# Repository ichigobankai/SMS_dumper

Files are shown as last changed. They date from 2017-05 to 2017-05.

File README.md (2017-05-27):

# SMS dumper

This project is a very low cost USB reader/writer(1) for Sega Master System cartridges.
HID code is based on libopencm3 ARM Lib & paulfertser/stm32-tx-hid ( https://github.com/paulfertser/stm32-tx-hid)

Support :
* Sega Master System mapper (Sms/Mark3, SG-1000/SC-3000/Othello Multivision)
* Codemasters mapper
* Korean "large" mapper (type Jang Pung III)
* Read and write S-ram (Master System Mapper)
* can re-write flash eprom on my pcb(1)

Speed (can vary depend on USB) :
* Dump 128kB : 4s
* write 128kB : 21s (erase/write and verif)(1)

(1)only working with my sega mapper clone/pcb

This firmware is targetting the cheapest STM32F103 board as found in
numerous listings on eBay and Aliexpress (might have the following
keywords: ARM STM32F103C8T6 Minimum System Development Board Module
For Arduino).

* Board description
The board has an STM32F103C8T6 controller for USB communication
(no drivers needed, connected in HID) 
It uses two 74LS273 for multiplexing i/o data lines into address lines.

* Building the firmware
After cloning the repository "git submodule init; git submodule
update" needs to be run once, then "build.sh" to build everything
necessary.

It is assumed that "arm-none-eabi" toolchain is available in PATH,
"GCC ARM Embedded" is the recommended option. In case you need to
specify a path, CROSS_COMPILE make variable should be set
appropriately.

* Initial flashing procedure
There're two ways of flashing a blank board: via SWD and via serial
bootloader. For the first method a suitable debug adapter is needed
(e.g. ST-Link or J-Link), for the second one can use just about any
USB-UART bridge (the only requirement that is a bit unusual is to
support "even" parity).

The image to be flashed is "smsdumper_stm32_bootANDsoft.bin", it
contains both a DFU-compliant bootloader and the main firmware. 

If you have any suggestions or questions, feel free to contact me
directly via email.

Ichigo <github@ultimate-consoles.fr>

My friend X-death have made a silimar dumper but for Megadrive/Genesis (Md Dumper)

Available on his Github page : https://github.com/X-death25/STM32_Projects/tree/master/Megadrive_HID

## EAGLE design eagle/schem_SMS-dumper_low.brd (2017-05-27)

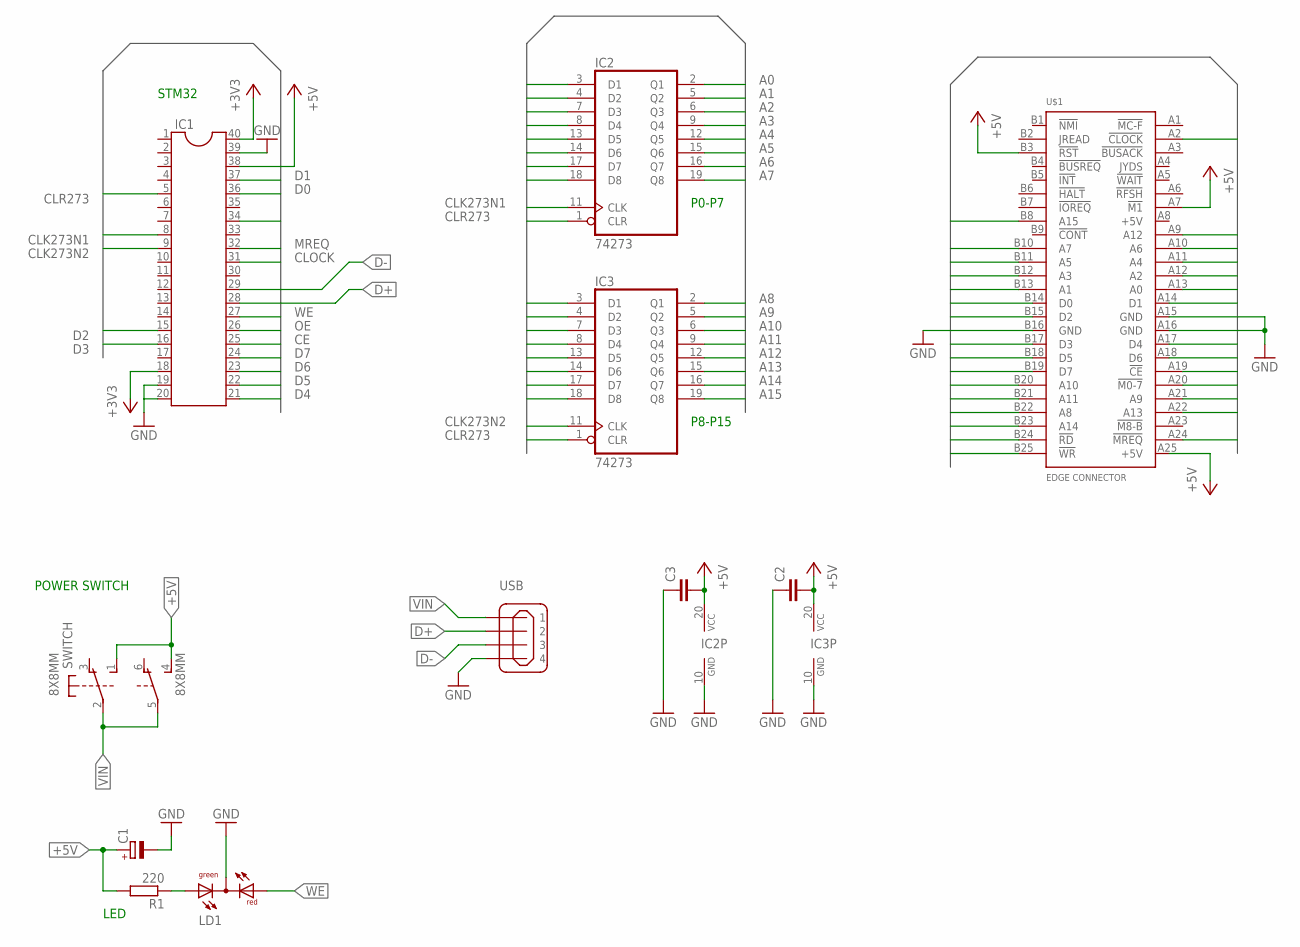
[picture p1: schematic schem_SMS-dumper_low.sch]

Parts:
8X8MM: SWITCH; PVA2F
C1: CPOL-EUE2,5-6E; E2,5-6E
C2, C3: C-EU050-024X044; C050-024X044
IC1: DIL40
IC2, IC3: 74273; DIL20
LD1: DUOLED-RG-C; DUOLED-C-5MM
R1: 220; 0204/7
U$1: EDGE CONNECTOR; CARD50F
USB: MINI-USB_4P-85-32004-10X; 85-32004-10X

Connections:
+3V3: IC1.18, IC1.40
+5V: 8X8MM.1 (S), 8X8MM.4 (S), C1.+, C2.2, C3.2, IC1.38, IC2.20 (VCC), IC3.20 (VCC), R1.2, U$1.A7 (!M1), U$1.A25 (+5V), U$1.B3 (!RST)
A0: IC2.2 (Q1), U$1.A13 (A0)
A1: IC2.5 (Q2), U$1.B13 (A1)
A2: IC2.6 (Q3), U$1.A12 (A2)
A3: IC2.9 (Q4), U$1.B12 (A3)
A4: IC2.12 (Q5), U$1.A11 (A4)
A5: IC2.15 (Q6), U$1.B11 (A5)
A6: IC2.16 (Q7), U$1.A10 (A6)
A7: IC2.19 (Q8), U$1.B10 (A7)
A8: IC3.2 (Q1), U$1.B22 (A8)
A9: IC3.5 (Q2), U$1.A21 (A9)
A10: IC3.6 (Q3), U$1.B20 (A10)
A11: IC3.9 (Q4), U$1.B21 (A11)
A12: IC3.12 (Q5), U$1.A9 (A12)
A13: IC3.15 (Q6), U$1.A22 (A13)
A14: IC3.16 (Q7), U$1.B23 (A14)
A15: IC3.19 (Q8), U$1.B8 (A15)
CE: IC1.25, U$1.A19 (!CE)
CLK273N1: IC1.8, IC2.11 (CLK)
CLK273N2: IC1.9, IC3.11 (CLK)
CLOCK: IC1.31, U$1.A2 (!CLOCK)
CLR273: IC1.5, IC2.1 (CLR), IC3.1 (CLR)
D0: IC1.36, IC2.3 (D1), IC3.3 (D1), U$1.B14 (D0)
D1: IC1.37, IC2.4 (D2), IC3.4 (D2), U$1.A14 (D1)
D2: IC1.15, IC2.7 (D3), IC3.7 (D3), U$1.B15 (D2)
D3: IC1.16, IC2.8 (D4), IC3.8 (D4), U$1.B17 (D3)
D4: IC1.21, IC2.13 (D5), IC3.13 (D5), U$1.A17 (D4)
D5: IC1.22, IC2.14 (D6), IC3.14 (D6), U$1.B18 (D5)
D6: IC1.23, IC2.17 (D7), IC3.17 (D7), U$1.A18 (D6)
D7: IC1.24, IC2.18 (D8), IC3.18 (D8), U$1.B19 (D7)
D+: IC1.28, USB.2
D-: IC1.29, USB.3
GND: C1.-, C2.1, C3.1, IC1.19, IC1.20, IC1.39, IC2.10 (GND), IC3.10 (GND), U$1.A15 (GND), U$1.A16 (GND), U$1.B16 (GND), USB.4
M0-7: IC1.34, U$1.A20 (!M0-7)
MREQ: IC1.32, U$1.A24 (!MREQ)
unnamed: LD1.AX (AG), R1.1
OE: IC1.26, U$1.B24 (!RD)
VIN: 8X8MM.2, 8X8MM.5, USB.1
WE: IC1.27, LD1.AR, U$1.B25 (!WR)

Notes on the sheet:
STM32
P0-P7
P8-P15
POWER SWITCH
LED

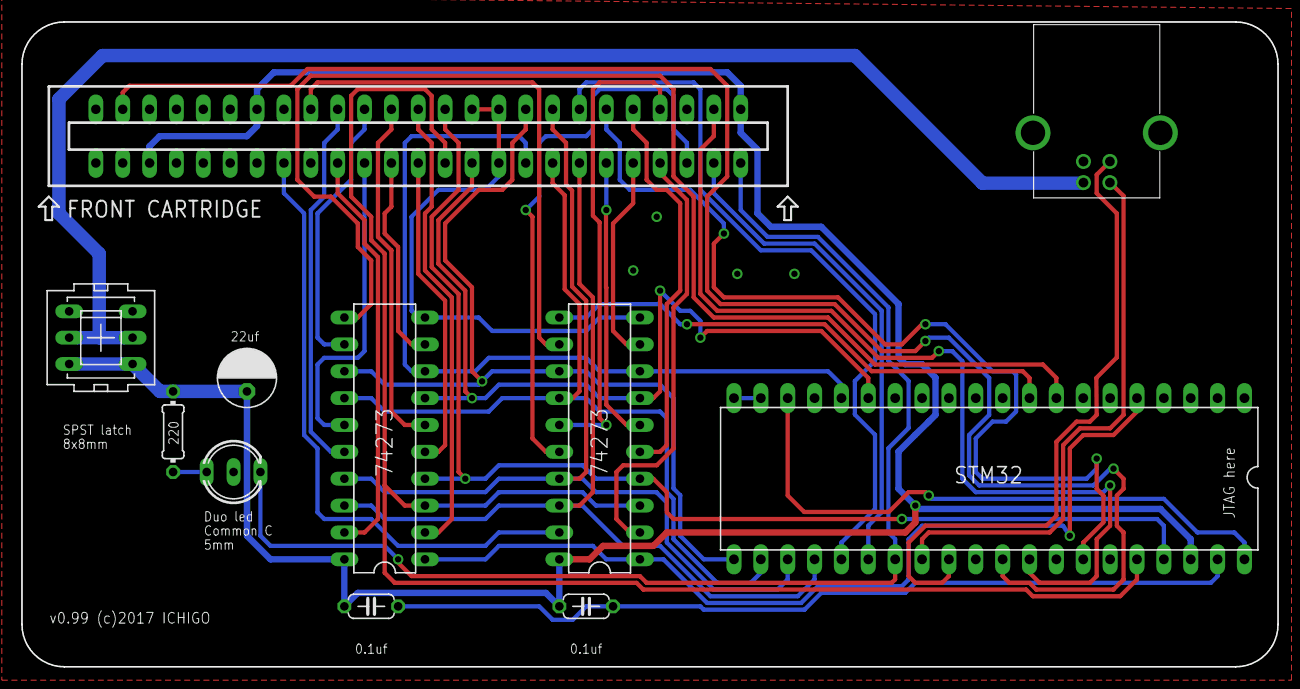
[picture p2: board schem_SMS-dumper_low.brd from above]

Board: 2 copper layers, 118.7 x 61.0 mm, 11 parts (0 on the bottom side), 40 nets.

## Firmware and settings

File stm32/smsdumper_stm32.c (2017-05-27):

/*  
SMS dumper v0
STM32F103CT8
*/

#include <string.h>
#include <libopencm3/stm32/rcc.h>
#include <libopencm3/stm32/exti.h>
#include <libopencm3/stm32/gpio.h>
#include <libopencm3/stm32/flash.h>
#include <libopencm3/stm32/adc.h>
#include <libopencm3/stm32/pwr.h>
#include <libopencm3/usb/usbd.h>
#include <libopencm3/usb/hid.h>
#include <libopencm3/stm32/st_usbfs.h>
#include <libopencm3/cm3/systick.h>
#include <libopencm3/cm3/nvic.h>
#include <libopencmsis/core_cm3.h>

#include <libopencm3/cm3/scb.h>
#include <libopencm3/usb/dfu.h>

#define D0 GPIO8  // PB8
#define D1 GPIO9  // PB9
#define D2 GPIO10 // PB10
#define D3 GPIO11 // PB11
#define D4 GPIO12 // PB12
#define D5 GPIO13 // PB13
#define D6 GPIO14 // PB14
#define D7 GPIO15 // PB15

#define CE GPIO8  //PA8
#define OE GPIO9  //PA9
#define WE GPIO10 //PA10

#define CLOCK GPIO3 //PB3  	- only for codemasters
#define MREQ GPIO4 //PB4   	- only for codemasters and MK3
#define M7 GPIO6 //PB6		- M0-7

#define CLEAR_273 GPIO0  // PA0
#define CLK_273N1 GPIO3  // PA3 
#define CLK_273N2 GPIO4  // PA4

#define SMS_WAKEUP    		0x11  // WakeUP STM32
#define SMS_READ      		0x12  // Read
#define SMS_WRITE_SRAM     	0x13  // Write
#define SMS_WRITE_FLASH     0x14  // Write Flash
#define SMS_ERASE_FLASH     0x15  // Write Flash
//#define SMS_FLASH_ID   	  	0x16  // Chip ID

#define CLEAR_ALL_PINS	0x44444444

// We need a special large control buffer for this device:
unsigned char usbd_control_buffer[5*64];

unsigned char buffer_in[64];
unsigned char buffer_out[64];
const unsigned char buffer_zeroed[64] = {0}; 
unsigned char hid_interrupt = 0;
unsigned int address = 0; //0xFFFF max

static usbd_device *usbd_dev;
static char serial_no[25];

const struct usb_device_descriptor dev_descr =
{
    .bLength = USB_DT_DEVICE_SIZE,
    .bDescriptorType = USB_DT_DEVICE,
    .bcdUSB = 0x0200,
    .bDeviceClass = 0,
    .bDeviceSubClass = 0,
    .bDeviceProtocol = 0,
    .bMaxPacketSize0 = 64,
    .idVendor = 0x0483,
    .idProduct = 0x5750,
    .bcdDevice = 0x0200,
    .iManufacturer = 1,
    .iProduct = 2,
    .iSerialNumber = 3,
    .bNumConfigurations = 1,
};

static const uint8_t hid_report_descriptor[] =
{

    0x06, 0x00, 0xFF,  // Usage Page (Vendor Defined 0xFF00)
    0x09, 0x01,        // Usage (0x01)
    0xA1, 0x01,        // Collection (Application)
    0x19, 0x01,        // Usage Minimum (0x01)
    0x29, 0x40,        // Usage Maximum (0x40)
    0x15, 0x00,        // Logical Minimum (0)
    0x26, 0xFF, 0x00,  // Logical Maximum (255)
    0x75, 0x08,        // Report Size (8)
    0x95, 0x40,        // Report Count (64)
    0x81, 0x00,        // Input (Data,Array,Abs,No Wrap,Linear,Preferred State,No Null Position)
    0x19, 0x01,        // Usage Minimum (0x01)
    0x29, 0x40,        // Usage Maximum (0x40)
    0x91, 0x00,        // Output (Data,Array,Abs,No Wrap,Linear,Preferred State,No Null Position,Non-volatile)
    0xC0,              // End Collection
};

static const struct
{
    struct usb_hid_descriptor hid_descriptor;
    struct
    {
        uint8_t bReportDescriptorType;
        uint16_t wDescriptorLength;
    } __attribute__((packed)) hid_report;
} __attribute__((packed)) hid_function =
{
    .hid_descriptor = {
        .bLength = sizeof(hid_function),
        .bDescriptorType = USB_DT_HID,
        .bcdHID = 0x0100,
        .bCountryCode = 0,
        .bNumDescriptors = 1,
    },
    .hid_report = {
        .bReportDescriptorType = USB_DT_REPORT,
        .wDescriptorLength = sizeof(hid_report_descriptor),
    }
};

const struct usb_endpoint_descriptor hid_endpoint[] =
{
    {
        .bLength = USB_DT_ENDPOINT_SIZE,
        .bDescriptorType = USB_DT_ENDPOINT,
        .bEndpointAddress = 0x81,
        .bmAttributes = USB_ENDPOINT_ATTR_INTERRUPT,
        .wMaxPacketSize = 64,
        .bInterval = 0x01,
    },
    {
        .bLength = USB_DT_ENDPOINT_SIZE,
        .bDescriptorType = USB_DT_ENDPOINT,
        .bEndpointAddress = 0x01,
        .bmAttributes = USB_ENDPOINT_ATTR_INTERRUPT,
        .wMaxPacketSize = 64,
        .bInterval = 0x01,
    }

};

const struct usb_interface_descriptor hid_iface =
{
    .bLength = USB_DT_INTERFACE_SIZE,
    .bDescriptorType = USB_DT_INTERFACE,
    .bInterfaceNumber = 0,
    .bAlternateSetting = 0,
    .bNumEndpoints = 2,
    .bInterfaceClass = USB_CLASS_HID,
    .bInterfaceSubClass = 0, // boot
    .bInterfaceProtocol = 0, // mouse
    .iInterface = 0,

    .endpoint = hid_endpoint, // fix 2

    .extra = &hid_function,
    .extralen = sizeof(hid_function),
};

const struct usb_dfu_descriptor dfu_function =
{
    .bLength = sizeof(struct usb_dfu_descriptor),
    .bDescriptorType = DFU_FUNCTIONAL,
    .bmAttributes = USB_DFU_CAN_DOWNLOAD | USB_DFU_WILL_DETACH,
    .wDetachTimeout = 255,
    .wTransferSize = 1024,
    .bcdDFUVersion = 0x011A,
};

const struct usb_interface_descriptor dfu_iface =
{
    .bLength = USB_DT_INTERFACE_SIZE,
    .bDescriptorType = USB_DT_INTERFACE,
    .bInterfaceNumber = 1,
    .bAlternateSetting = 0,
    .bNumEndpoints = 0,
    .bInterfaceClass = 0xFE,
    .bInterfaceSubClass = 1,
    .bInterfaceProtocol = 1,
    // The ST Microelectronics DfuSe application needs this string.
    // The format isn't documented...
    .iInterface = 4,

    .extra = &dfu_function,
    .extralen = sizeof(dfu_function),
};

const struct usb_interface ifaces[] = {{
        .num_altsetting = 1,
        .altsetting = &hid_iface,
    }, {
        .num_altsetting = 1,
        .altsetting = &dfu_iface,
    }
};

const struct usb_config_descriptor config =
{
    .bLength = USB_DT_CONFIGURATION_SIZE,
    .bDescriptorType = USB_DT_CONFIGURATION,
    .wTotalLength = 0,
    .bNumInterfaces = 2,
    .bConfigurationValue = 1,
    .iConfiguration = 0,
    .bmAttributes = 0xC0,
    .bMaxPower = 0x32,

    .interface = ifaces,
};

static int hid_control_request(usbd_device *dev, struct usb_setup_data *req, uint8_t **buf, uint16_t *len,
                               void (**complete)(usbd_device *dev, struct usb_setup_data *req))
{
    (void)complete;
    (void)dev;

    if((req->bmRequestType != 0x81) ||
            (req->bRequest != USB_REQ_GET_DESCRIPTOR) ||
            (req->wValue != 0x2200))
        return 0;

    // Handle the HID report descriptor.
    *buf = (uint8_t *)hid_report_descriptor;
    *len = sizeof(hid_report_descriptor);

    return 1;
}

static void dfu_detach_complete(usbd_device *dev, struct usb_setup_data *req)
{
    (void)req;
    (void)dev;

    scb_reset_core();
}

static int dfu_control_request(usbd_device *dev, struct usb_setup_data *req, uint8_t **buf, uint16_t *len,
                               void (**complete)(usbd_device *dev, struct usb_setup_data *req))
{
    (void)buf;
    (void)len;
    (void)dev;

    if ((req->bmRequestType != 0x21) || (req->bRequest != DFU_DETACH))
        return 0; // Only accept class request.

    *complete = dfu_detach_complete;

    return 1;
}

static void hid_set_config(usbd_device *dev, uint16_t wValue)
{
    (void)wValue;

    usbd_ep_setup(dev, 0x81, USB_ENDPOINT_ATTR_INTERRUPT, 64, NULL);
    usbd_ep_setup(dev, 0x01, USB_ENDPOINT_ATTR_INTERRUPT, 64, NULL);

    usbd_register_control_callback(
        dev,
        USB_REQ_TYPE_STANDARD | USB_REQ_TYPE_INTERFACE,
        USB_REQ_TYPE_TYPE | USB_REQ_TYPE_RECIPIENT,
        hid_control_request);
    usbd_register_control_callback(
        dev,
        USB_REQ_TYPE_CLASS | USB_REQ_TYPE_INTERFACE,
        USB_REQ_TYPE_TYPE | USB_REQ_TYPE_RECIPIENT,
        dfu_control_request);

    //systick configuration

    // 72MHz / 8 => 9000000 counts per second : 9 Mhz
    systick_set_clocksource(STK_CSR_CLKSOURCE_AHB_DIV8);
    STK_CVR = 0;
    systick_set_reload(8999);
    systick_interrupt_enable();
    systick_counter_enable();
}

static const char *usb_strings[] =
{
    "libopencm3",
    "SMS Dumper",
    serial_no,
    // This string is used by ST Microelectronics' DfuSe utility.
    "@Internal Flash   /0x08000000/8*001Ka,56*001Kg",
};

static char *get_dev_unique_id(char *s)
{
    volatile uint8_t *unique_id = (volatile uint8_t *)0x1FFFF7E8;
    int i;

    // Fetch serial number from chip's unique ID
    for(i = 0; i < 24; i+=2)
    {
        s[i] = ((*unique_id >> 4) & 0xF) + '0';
        s[i+1] = (*unique_id++ & 0xF) + '0';
    }
    for(i = 0; i < 24; i++)
        if(s[i] > '9')
            s[i] += 'A' - '9' - 1;

    return s;
}



void wait(unsigned char n){
    while(n){ 
    	__asm__("nop"); 
    	n--;
    }
}


void enable_cart(){
	GPIO_BRR(GPIOA) |= (CE | OE);
}

void disable_cart(){
	GPIO_BSRR(GPIOA) |= (CE | OE);
}


void mapper_write_register(){
	
    //set adr MAPPER register
    GPIO_CRH(GPIOB) = 0x33333333; //set pb8-15 as data OUT
  
    GPIO_ODR(GPIOB) = (buffer_in[5]<<8); //MAPPER adr low
    GPIO_BRR(GPIOA)  |= CLK_273N1;
    GPIO_BSRR(GPIOA) |= CLK_273N1;

    GPIO_ODR(GPIOB) = (buffer_in[6]<<8); //MAPPER adr hi
   	GPIO_BRR(GPIOA)  |= CLK_273N2;
   	GPIO_BSRR(GPIOA) |= CLK_273N2;
   	
    GPIO_ODR(GPIOB) = (buffer_in[4]<<8); //MAPPER page D0-D7
   	enable_cart();
	if((buffer_in[7]==3 && address>0x7FFF) && hid_interrupt==SMS_READ){  //4Pak mapper
		GPIO_BSRR(GPIOB) |= M7 | (MREQ << 16); 
		}else{ 
		GPIO_BRR(GPIOB) |= M7 | MREQ; 
	}
	if(buffer_in[7]==1 && hid_interrupt==SMS_READ){ GPIO_BSRR(GPIOB) |= M7; }
	GPIO_BRR(GPIOA) |= WE;
	if(buffer_in[7]==2 && hid_interrupt==SMS_READ){ //codemasters mapper
		GPIO_BRR(GPIOB) |= CLOCK;
		GPIO_BSRR(GPIOB) |= CLOCK;
	}
    __asm__("nop");
	GPIO_BSRR(GPIOA) |= WE;
	disable_cart();
}


void read_cartridge(){
  	unsigned char adr = 0;

    GPIO_CRL(GPIOA) = 0x44433443; //out Clk1-3, et MRclear
	GPIO_CRH(GPIOA) = 0x44444333; //all out CE, etc. 50mhz
	GPIO_CRL(GPIOB) = 0x43433444;  //set clock/mreq for codemasters mapper, M0-7(=A15 on some MS old games)
  	
	//Clk273n1, Clk273n2, Clk273n3, WE = High - Clear273
  	GPIO_BSRR(GPIOA) |= (CLK_273N1 | CLK_273N2 | WE | CE | OE) | (CLEAR_273 << 16);
    GPIO_BSRR(GPIOA) |= CLEAR_273; //active 273.
	
	if(buffer_in[7]==2){ //codemasters
		GPIO_BSRR(GPIOB) |= CLOCK | (MREQ << 16); 
	}
	
	if(buffer_in[3]){ mapper_write_register(); }

 	while(adr < 64){
        GPIO_CRH(GPIOB) = 0x33333333; //set pb8-15 as data OUT

        //adr A0-A7
        GPIO_ODR(GPIOB) = ((address +adr) & 0xFF) << 8; //address LSB
	    GPIO_BRR(GPIOA) |= CLK_273N1; //low
	    GPIO_BSRR(GPIOA) |= CLK_273N1; //high
        
        //adr A8-A15
        GPIO_ODR(GPIOB) = (address +adr) & 0xFF00; //address MSB
    	GPIO_BRR(GPIOA) |= CLK_273N2; //low
    	GPIO_BSRR(GPIOA) |= CLK_273N2; //high
		

		if(buffer_in[7]==1 && address>0x7FFF){ GPIO_BSRR(GPIOB) |= M7; }else{ GPIO_BRR(GPIOB) |= M7; }
//		if(buffer_in[7]==3 && address>0x7FFF){ GPIO_BSRR(GPIOB) |= M7; }else{ GPIO_BRR(GPIOB) |= M7; }

        GPIO_CRH(GPIOB) = 0x44444444; //set pb8-15 as data IN
		
		enable_cart();
        wait(16);      
        buffer_out[adr] = (GPIO_IDR(GPIOB) & 0xFF00) >> 8; //save into buffer
		disable_cart();
		adr++; //next adr/byte
  	}
  	//clear all IO
    GPIO_CRL(GPIOA) = CLEAR_ALL_PINS;
    GPIO_CRH(GPIOA) = CLEAR_ALL_PINS;
	GPIO_CRH(GPIOB) = CLEAR_ALL_PINS;

}

void write_sram(){
  	unsigned char adr = 0;

    GPIO_CRL(GPIOA) = 0x44433443; //out Clk1-3, et MRclear
    GPIO_CRH(GPIOA) = 0x44444333; //all out CE, etc. 50mhz

  	GPIO_BSRR(GPIOA) |= (CLK_273N1 | CLK_273N2 | WE | CE | OE) | (CLEAR_273 << 16);
    GPIO_BSRR(GPIOA) |= CLEAR_273; //active 273.
	
	mapper_write_register(); //place & activ SRAM   	
   	
   	while(adr < 32){
		
		//PLACE ADR to WRITE
      	GPIO_ODR(GPIOB) = ((address +adr) & 0xFF) << 8; //address LSB
	    GPIO_BRR(GPIOA) |= CLK_273N1; //low
	    GPIO_BSRR(GPIOA) |= CLK_273N1; //high
	           
        GPIO_ODR(GPIOB) = (address +adr) & 0xFF00; //address MSB
    	GPIO_BRR(GPIOA) |= CLK_273N2; //low
    	GPIO_BSRR(GPIOA) |= CLK_273N2; //high
   	
   		GPIO_ODR(GPIOB) = 0;
   		
		//PLACE BYTE to WRITE
		enable_cart();
		GPIO_BRR(GPIOA) |= WE;
	    GPIO_ODR(GPIOB) = (buffer_in[(adr +7)]<<8);
		GPIO_BSRR(GPIOA) |= WE;
		disable_cart();
	   	adr++; //next adr/byte
	}
  	//clear all IO
    GPIO_CRL(GPIOA) = CLEAR_ALL_PINS;
    GPIO_CRH(GPIOA) = CLEAR_ALL_PINS;
	GPIO_CRH(GPIOB) = CLEAR_ALL_PINS;

}


void command_write_flash(unsigned int flash_adr, unsigned char flash_val){

	GPIO_ODR(GPIOB) = ((flash_adr & 0xFF)<<8); //adr flash lo
    GPIO_BRR(GPIOA) |= CLK_273N1;
    GPIO_BSRR(GPIOA) |= CLK_273N1;

    GPIO_ODR(GPIOB) = (flash_adr & 0xFF00); //adr flash hi
   	GPIO_BRR(GPIOA) |= CLK_273N2;
   	GPIO_BSRR(GPIOA) |= CLK_273N2;
	
	GPIO_ODR(GPIOB) = (flash_val << 8);
	GPIO_BRR(GPIOA) |= WE;	//set adr
	wait(16);
	GPIO_BSRR(GPIOA) |= WE; //set data
}


void erase_flash(){
	unsigned long timeout = 0x400000;
	
    GPIO_CRL(GPIOA) = 0x44433443; //out Clk1-3, et MRclear
    GPIO_CRH(GPIOA) = 0x44444333; //all out CE, etc. 50mhz

  	GPIO_BSRR(GPIOA) |= (CLK_273N1 | CLK_273N2 | WE | CE) | (CLEAR_273 << 16);
    GPIO_BSRR(GPIOA) |= CLEAR_273; //active 273.
   
    GPIO_CRH(GPIOB) = 0x33333333; //set pb8-15 as data OUT
	wait(16);
	
	command_write_flash(0x5555, 0xAA); 
	command_write_flash(0x2AAA, 0x55); 
	command_write_flash(0x5555, 0x80); 
	command_write_flash(0x5555, 0xAA); 
	command_write_flash(0x2AAA, 0x55); 
	command_write_flash(0x5555, 0x10); 
	
    while(timeout){ __asm__("nop"); timeout--; }

    GPIO_CRL(GPIOA) = CLEAR_ALL_PINS;
    GPIO_CRH(GPIOA) = CLEAR_ALL_PINS;
	GPIO_CRH(GPIOB) = CLEAR_ALL_PINS;

}


void write_flash(){
  	unsigned char adr = 0; //start @7
	unsigned char prg_val = 0;
	unsigned int prg_adr = 0;
	
    GPIO_CRL(GPIOA) = 0x44433443; //out Clk1-3, et MRclear
    GPIO_CRH(GPIOA) = 0x44444333; //all out CE, etc. 50mhz

  	GPIO_BSRR(GPIOA) |= (CLK_273N1 | CLK_273N2 | WE | CE ) | (CLEAR_273 << 16);
    GPIO_BSRR(GPIOA) |= CLEAR_273; //active 273.
		
	mapper_write_register();

   	while(adr < 32){
   		prg_adr = address+adr;
   		prg_val = buffer_in[(adr +7)];

  		if(prg_val!=0xFF){ //skip 0xFF to boost
			command_write_flash(0x5555, 0xAA); 
			command_write_flash(0x2AAA, 0x55); 
			command_write_flash(0x5555, 0xA0); 
			command_write_flash(prg_adr, prg_val); 
		    for(unsigned int timeout=0; timeout<0x140; timeout++){ __asm__("nop"); }
  		}	
		adr++; //next adr/byte
	}
	
  	//clear all IO
    GPIO_CRL(GPIOA) = CLEAR_ALL_PINS;
    GPIO_CRH(GPIOA) = CLEAR_ALL_PINS;
	GPIO_CRH(GPIOB) = CLEAR_ALL_PINS;
 
}

/*
void flash_id(){
	
    GPIO_CRL(GPIOA) = 0x44433443; //out Clk1-3, et MRclear
    GPIO_CRH(GPIOA) = 0x44444333; //all out CE, etc. 50mhz

  	GPIO_BSRR(GPIOA) |= (CLK_273N1 | CLK_273N2 | WE | CE ) | (CLEAR_273 << 16);
    GPIO_BSRR(GPIOA) |= CLEAR_273; //active 273.

	//ENTRY chip ID
    GPIO_CRH(GPIOB) = 0x33333333; //as out
	command_write_flash(0x5555, 0xAA);
	command_write_flash(0x2AAA, 0x55);
	command_write_flash(0x5555, 0x90);
   	
   	wait(150);
   		
    GPIO_ODR(GPIOB) = 0;
	GPIO_BRR(GPIOA) |= CLK_273N1;
    GPIO_BSRR(GPIOA) |= CLK_273N1;
   	GPIO_BRR(GPIOA) |= CLK_273N2;
   	GPIO_BSRR(GPIOA) |= CLK_273N2; 
   			
	GPIO_CRH(GPIOB) = 0x44444444; //as in
 	GPIO_BRR(GPIOA) |= CE;
    buffer_out[0] = (GPIO_IDR(GPIOB) & 0xFF00) >> 8; //save buffer
 	GPIO_BSRR(GPIOA) |= CE;
//
//    GPIO_CRH(GPIOB) = 0x33333333; //as out
//    GPIO_ODR(GPIOB) = 1;
//	GPIO_BRR(GPIOA) |= CLK_273N1;
//    GPIO_BSRR(GPIOA) |= CLK_273N1;
//   	GPIO_BRR(GPIOA) |= CLK_273N2;
//   	GPIO_BSRR(GPIOA) |= CLK_273N2;	
//	GPIO_CRH(GPIOB) = 0x44444444; //as in
//	
// 	GPIO_BRR(GPIOA) |= CE;
//    buffer_out[1] = (GPIO_IDR(GPIOB) & 0xFF00) >> 8; //save buffer
// 	GPIO_BSRR(GPIOA) |= CE;
//
    buffer_out[2] = 0xFF; //save into buffer

	//EXIT chip ID
    GPIO_CRH(GPIOB) = 0x33333333; //as out
	command_write_flash(0x5555, 0xAA); 
	command_write_flash(0x2AAA, 0x55); 
	command_write_flash(0x5555, 0xF0); 
		
    GPIO_CRL(GPIOA) = CLEAR_ALL_PINS;
    GPIO_CRH(GPIOA) = CLEAR_ALL_PINS;
	GPIO_CRH(GPIOB) = CLEAR_ALL_PINS;	

}
*/

static void usb_suspend_callback(){
    *USB_CNTR_REG |= USB_CNTR_FSUSP;
    *USB_CNTR_REG |= USB_CNTR_LP_MODE;
    SCB_SCR |= SCB_SCR_SLEEPDEEP;
    __WFI();
}

void usb_wakeup_isr(){
    exti_reset_request(EXTI18);
    rcc_clock_setup_in_hse_8mhz_out_72mhz();
    *USB_CNTR_REG &= ~USB_CNTR_FSUSP;
}


// Function Called Every Ticks

void sys_tick_handler(void){
    
    if(hid_interrupt == 1){
		buffer_in[0] = 0;
        usbd_ep_read_packet(usbd_dev, 0x01, buffer_in, sizeof(buffer_in));
        
        switch(buffer_in[0]){
	        case SMS_WAKEUP:
	        case SMS_READ:
	        case SMS_WRITE_SRAM:
	        case SMS_WRITE_FLASH:
	        case SMS_ERASE_FLASH:
//	        case SMS_FLASH_ID: 	
	        	hid_interrupt = buffer_in[0]; break;
	        	
	        default: 
	        	memcpy((unsigned char *)buffer_in, (unsigned char *)buffer_zeroed, sizeof(buffer_in));
				hid_interrupt = 1;	        	
        }
    }
}


int main(void){
    rcc_clock_setup_in_hse_8mhz_out_72mhz();

    rcc_periph_clock_enable(RCC_GPIOA);
    rcc_periph_clock_enable(RCC_GPIOB);
    rcc_periph_clock_enable(RCC_GPIOC);

    /* Enable alternate function peripheral clock. */
    rcc_periph_clock_enable(RCC_AFIO);

    /* Interrupt for USB */
    exti_set_trigger(EXTI18, EXTI_TRIGGER_RISING);
    exti_enable_request(EXTI18);
    nvic_enable_irq(NVIC_USB_WAKEUP_IRQ);

    /*Setup Programming mode */
    gpio_set_mode(GPIOC, GPIO_MODE_INPUT, GPIO_CNF_INPUT_FLOAT, GPIO14);
    gpio_set_mode(GPIOC, GPIO_MODE_OUTPUT_10_MHZ,GPIO_CNF_OUTPUT_PUSHPULL, GPIO13);
	//led clignotante programming mode
    if (GPIOC_IDR & GPIO14){
        while(1){
            AFIO_MAPR |= AFIO_MAPR_SWJ_CFG_FULL_SWJ_NO_JNTRST;
            gpio_toggle(GPIOC, GPIO13);	/* LED on/off */
            for(unsigned long i = 0; i < 0x100000; i++){ __asm__("nop"); }
        }
    }

    gpio_set_mode(GPIOA, GPIO_MODE_OUTPUT_2_MHZ, GPIO_CNF_OUTPUT_PUSHPULL, GPIO12);
    gpio_clear(GPIOA, GPIO12);

    for(unsigned long i = 0; i < 0x800000; i++){ __asm__("nop"); } //1sec
	gpio_clear(GPIOC, GPIO13);

    get_dev_unique_id(serial_no);

    usbd_dev = usbd_init(&st_usbfs_v1_usb_driver, &dev_descr, &config, usb_strings, 4, usbd_control_buffer, sizeof(usbd_control_buffer));
    usbd_register_set_config_callback(usbd_dev, hid_set_config);
    usbd_register_suspend_callback(usbd_dev, usb_suspend_callback);

	//Full GPIO
	AFIO_MAPR = AFIO_MAPR_SWJ_CFG_JTAG_OFF_SW_OFF;

    //clear pins
    GPIO_CRL(GPIOA) = CLEAR_ALL_PINS;
    GPIO_CRH(GPIOA) = CLEAR_ALL_PINS;
    GPIO_CRL(GPIOB) = CLEAR_ALL_PINS;
    GPIO_CRH(GPIOB) = CLEAR_ALL_PINS;
	
	hid_interrupt = 1;
	
    while(1){
       
        usbd_poll(usbd_dev);
   		
   		//WAKEUP
   		switch(hid_interrupt){
   			
	   		case SMS_WAKEUP:
				buffer_out[0] = 0xFF;
				usbd_ep_write_packet(usbd_dev, 0x81, buffer_out, sizeof(buffer_out));
				buffer_out[0] = 0x0;
				hid_interrupt = 1;
				break;
				
        	case SMS_READ:
        		address = buffer_in[1] | (buffer_in[2]<<8);
				read_cartridge();
				usbd_ep_write_packet(usbd_dev, 0x81, buffer_out, 64);
				memcpy((unsigned char *)buffer_out, (unsigned char *)buffer_zeroed, 64);
				hid_interrupt = 1;
				break;			   		
   		
   			case SMS_WRITE_SRAM:
	        	address = buffer_in[1] | (buffer_in[2]<<8);
				write_sram();
				buffer_out[0] = 0xFF;
				usbd_ep_write_packet(usbd_dev, 0x81, buffer_out, 64);
				buffer_out[0] = 0x0;
	        	hid_interrupt = 1;
				break;
			
			case SMS_WRITE_FLASH:
				address = buffer_in[1] | (buffer_in[2]<<8);
				write_flash();
				buffer_out[0] = 0xFF;
				usbd_ep_write_packet(usbd_dev, 0x81, buffer_out, 64);
				buffer_out[0] = 0x0;
	        	hid_interrupt = 1;
	        	break;
        	
        	case SMS_ERASE_FLASH:
	        	erase_flash();
				buffer_out[0] = 0xFF;
				usbd_ep_write_packet(usbd_dev, 0x81, buffer_out, 64);
				buffer_out[0] = 0;
	        	hid_interrupt = 1;
	        	break;
        	/*
        	case SMS_FLASH_ID:
	        	flash_id();
				usbd_ep_write_packet(usbd_dev, 0x81, buffer_out, 64);
				memcpy((unsigned char *)buffer_out, (unsigned char *)buffer_zeroed, 64);
	        	hid_interrupt = 1;
	        	break;
	        */
   		
   		}

    }
}

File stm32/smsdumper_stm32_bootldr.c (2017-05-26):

/*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
 * You should have received a copy of the GNU General Public License
 * along with this program.  If not, see
 * <http://www.gnu.org/licenses/>.
 */

#include <string.h>
#include <libopencm3/stm32/rcc.h>
#include <libopencm3/stm32/gpio.h>
#include <libopencm3/stm32/flash.h>
#include <libopencm3/usb/usbd.h>
#include <libopencm3/stm32/st_usbfs.h>
#include <libopencm3/cm3/scb.h>
#include <libopencm3/usb/dfu.h>

#define FORCE_BOOT	(GPIO1 | GPIO5)

/* Commands sent with wBlockNum == 0 as per ST implementation. */
#define CMD_SETADDR	0x21
#define CMD_ERASE	0x41

/* We need a special large control buffer for this device: */
uint8_t usbd_control_buffer[1024];

static enum dfu_state usbdfu_state = STATE_DFU_IDLE;

static struct {
	uint8_t buf[sizeof(usbd_control_buffer)];
	uint16_t len;
	uint32_t addr;
	uint16_t blocknum;
} prog;

const struct usb_device_descriptor dev = {
	.bLength = USB_DT_DEVICE_SIZE,
	.bDescriptorType = USB_DT_DEVICE,
	.bcdUSB = 0x0200,
	.bDeviceClass = 0,
	.bDeviceSubClass = 0,
	.bDeviceProtocol = 0,
	.bMaxPacketSize0 = 64,
	.idVendor = 0x0483,
	.idProduct = 0xDF11,
	.bcdDevice = 0x0200,
	.iManufacturer = 1,
	.iProduct = 2,
	.iSerialNumber = 3,
	.bNumConfigurations = 1,
};

const struct usb_dfu_descriptor dfu_function = {
	.bLength = sizeof(struct usb_dfu_descriptor),
	.bDescriptorType = DFU_FUNCTIONAL,
	.bmAttributes = USB_DFU_CAN_DOWNLOAD | USB_DFU_WILL_DETACH,
	.wDetachTimeout = 255,
	.wTransferSize = 1024,
	.bcdDFUVersion = 0x011A,
};

const struct usb_interface_descriptor iface = {
	.bLength = USB_DT_INTERFACE_SIZE,
	.bDescriptorType = USB_DT_INTERFACE,
	.bInterfaceNumber = 0,
	.bAlternateSetting = 0,
	.bNumEndpoints = 0,
	.bInterfaceClass = 0xFE, /* Device Firmware Upgrade */
	.bInterfaceSubClass = 1,
	.bInterfaceProtocol = 2,

	/* The ST Microelectronics DfuSe application needs this string.
	 * The format isn't documented... */
	.iInterface = 4,

	.extra = &dfu_function,
	.extralen = sizeof(dfu_function),
};

const struct usb_interface ifaces[] = {{
	.num_altsetting = 1,
	.altsetting = &iface,
}};

const struct usb_config_descriptor config = {
	.bLength = USB_DT_CONFIGURATION_SIZE,
	.bDescriptorType = USB_DT_CONFIGURATION,
	.wTotalLength = 0,
	.bNumInterfaces = 1,
	.bConfigurationValue = 1,
	.iConfiguration = 0,
	.bmAttributes = 0xC0,
	.bMaxPower = 0x32,

	.interface = ifaces,
};

static char serial_no[25];

static const char *usb_strings[] = {
	"libopencm3",
	"STM32 Tx HID adapter (DFU)",
	serial_no,
	/* This string is used by ST Microelectronics' DfuSe utility. */
	"@Internal Flash   /0x08000000/8*001Ka,56*001Kg",
};

static char *get_dev_unique_id(char *s)
{
	volatile uint8_t *unique_id = (volatile uint8_t *)0x1FFFF7E8;
	int i;

	/* Fetch serial number from chip's unique ID */
	for(i = 0; i < 24; i+=2) {
		s[i] = ((*unique_id >> 4) & 0xF) + '0';
		s[i+1] = (*unique_id++ & 0xF) + '0';
	}
	for(i = 0; i < 24; i++)
		if(s[i] > '9')
			s[i] += 'A' - '9' - 1;

	return s;
}

static uint8_t usbdfu_getstatus(uint32_t *bwPollTimeout)
{
	switch (usbdfu_state) {
	case STATE_DFU_DNLOAD_SYNC:
		usbdfu_state = STATE_DFU_DNBUSY;
		*bwPollTimeout = 100;
		return DFU_STATUS_OK;
	case STATE_DFU_MANIFEST_SYNC:
		/* Device will reset when read is complete. */
		usbdfu_state = STATE_DFU_MANIFEST;
		return DFU_STATUS_OK;
	default:
		return DFU_STATUS_OK;
	}
}

static void usbdfu_getstatus_complete(usbd_device *usbd_dev, struct usb_setup_data *req)
{
	int i;
	(void)req;
	(void)usbd_dev;

	switch (usbdfu_state) {
	case STATE_DFU_DNBUSY:
		flash_unlock();
		if (prog.blocknum == 0) {
			switch (prog.buf[0]) {
			case CMD_ERASE:
				{
					uint32_t *dat = (uint32_t *)(prog.buf + 1);
					flash_erase_page(*dat);
				}
			case CMD_SETADDR:
				{
					uint32_t *dat = (uint32_t *)(prog.buf + 1);
					prog.addr = *dat;
				}
			}
		} else {
			uint32_t baseaddr = prog.addr + ((prog.blocknum - 2) *
				       dfu_function.wTransferSize);
			for (i = 0; i < prog.len; i += 2) {
				uint16_t *dat = (uint16_t *)(prog.buf + i);
				flash_program_half_word(baseaddr + i,
						*dat);
			}
		}
		flash_lock();

		/* Jump straight to dfuDNLOAD-IDLE, skipping dfuDNLOAD-SYNC. */
		usbdfu_state = STATE_DFU_DNLOAD_IDLE;
		return;
	case STATE_DFU_MANIFEST:
		return; /* Count on main loop to reset the board */
	default:
		return;
	}
}

static int usbdfu_control_request(usbd_device *usbd_dev, struct usb_setup_data *req, uint8_t **buf,
		uint16_t *len, void (**complete)(usbd_device *usbd_dev, struct usb_setup_data *req))
{
	(void)usbd_dev;

	if ((req->bmRequestType & 0x7F) != 0x21)
		return USBD_REQ_NEXT_CALLBACK; /* Only accept class request. */

	switch (req->bRequest) {
	case DFU_DNLOAD:
		if ((len == NULL) || (*len == 0)) {
			usbdfu_state = STATE_DFU_MANIFEST_SYNC;
			return USBD_REQ_HANDLED;
		} else {
			/* Copy download data for use on GET_STATUS. */
			prog.blocknum = req->wValue;
			prog.len = *len;
			memcpy(prog.buf, *buf, *len);
			usbdfu_state = STATE_DFU_DNLOAD_SYNC;
			return USBD_REQ_HANDLED;
		}
	case DFU_CLRSTATUS:
		/* Clear error and return to dfuIDLE. */
		if (usbdfu_state == STATE_DFU_ERROR)
			usbdfu_state = STATE_DFU_IDLE;
		return USBD_REQ_HANDLED;
	case DFU_ABORT:
		/* Abort returns to dfuIDLE state. */
		usbdfu_state = STATE_DFU_IDLE;
		return USBD_REQ_HANDLED;
	case DFU_DETACH:
		usbdfu_state = STATE_DFU_MANIFEST;
		return USBD_REQ_HANDLED;
	case DFU_UPLOAD:
		/* Upload not supported for now. */
		return USBD_REQ_NOTSUPP;
	case DFU_GETSTATUS: {
		uint32_t bwPollTimeout = 0; /* 24-bit integer in DFU class spec */
		(*buf)[0] = usbdfu_getstatus(&bwPollTimeout);
		(*buf)[1] = bwPollTimeout & 0xFF;
		(*buf)[2] = (bwPollTimeout >> 8) & 0xFF;
		(*buf)[3] = (bwPollTimeout >> 16) & 0xFF;
		(*buf)[4] = usbdfu_state;
		(*buf)[5] = 0; /* iString not used here */
		*len = 6;
		*complete = usbdfu_getstatus_complete;
		return USBD_REQ_HANDLED;
		}
	case DFU_GETSTATE:
		/* Return state with no state transision. */
		*buf[0] = usbdfu_state;
		*len = 1;
		return USBD_REQ_HANDLED;
	}

	return USBD_REQ_NEXT_CALLBACK;
}

static void usbdfu_set_config(usbd_device *usbd_dev, uint16_t wValue)
{
	(void)wValue;

	usbd_register_control_callback(
				usbd_dev,
				USB_REQ_TYPE_CLASS | USB_REQ_TYPE_INTERFACE,
				USB_REQ_TYPE_TYPE | USB_REQ_TYPE_RECIPIENT,
				usbdfu_control_request);
}
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

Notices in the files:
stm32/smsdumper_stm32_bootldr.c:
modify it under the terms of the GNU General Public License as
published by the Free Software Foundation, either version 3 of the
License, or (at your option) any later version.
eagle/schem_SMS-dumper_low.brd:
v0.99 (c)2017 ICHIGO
